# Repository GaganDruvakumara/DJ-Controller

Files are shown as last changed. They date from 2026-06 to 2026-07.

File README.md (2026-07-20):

# DIY DJ CONTROLLER
<body1 align="center">
  <br>
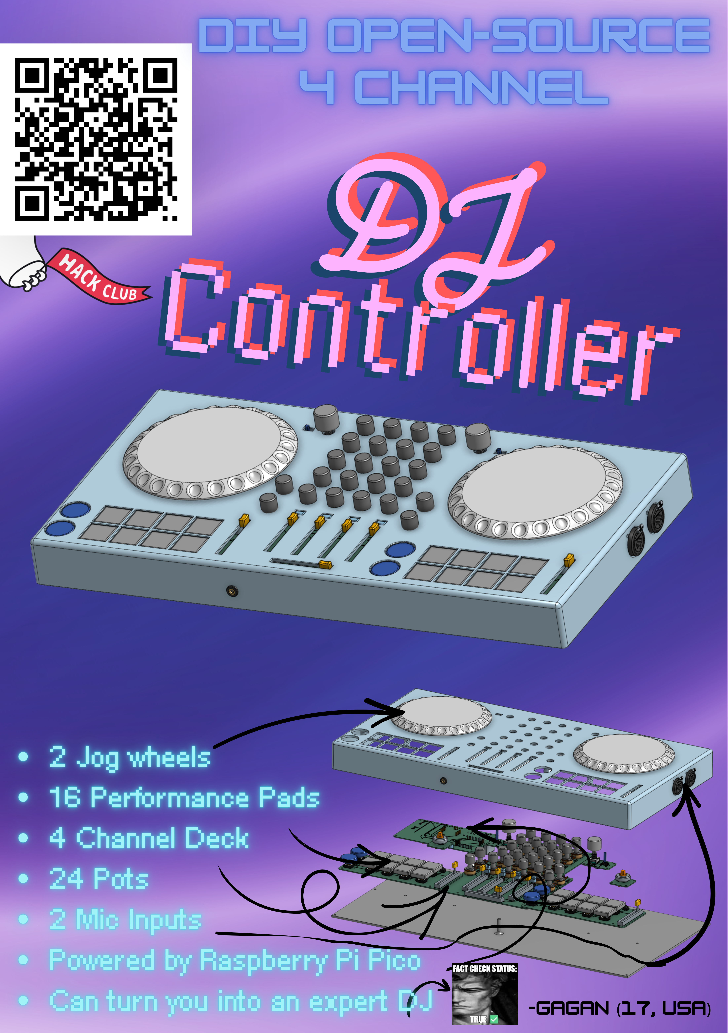
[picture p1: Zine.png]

  <br>
  I’ve wanted to get into this hobby for a while, but the cost of entry was a major barrier. I looked through existing projects online, but I couldn’t find any open-source DJ controllers that really stood out. Many were small, limited, or designed more like experimental gadgets rather than something practical for real DJ use. There seemed to be a gap between expensive commercial controllers and accessible open-source alternatives, which inspired me to create this project.
  <br>
  <br>
  <i>This project is a fully open-source, 4-channel DIY DJ controller designed to be a functional and customizable alternative for anyone interested in building their own hardware.</i>
</body1>

# Key Features
* 4 Channel Deck
* XLR & 6.35MM Jack L&R master out + 3.5mm Jack L+R master out
* 3.5mm Jack headphone out
* 32-bit DAC for outputs
* 2 Neutrik Jack Mic Inputs
* 24-bit ADC for inputs
* 16 performance pad with mode selector
* 2 rotary encoders for menu navigation

# PCB
7x 2-layer PCBs (9 total including duplicates) designed in KiCad
### PCB Schematic
PCB Schem

### PCB Front Layer


### PCB Back Layer


### PCB 3D View
Component models from GrabCad



## PCB Wiring Schematic


# CAD Assembly
CAD models designed in [Onshape](https://cad.onshape.com/documents/7791953f15b9474113af6284/w/087eac69f09fbec4411ed0d8/e/f1a33f0f3682f52a7b10a5d9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).
Assembly done with M3x5x5 threaded inserts & M3 screws. Countersunk screws are used to attach the backplate, otherwise use pan head screws for everything else.



# Bill of Materials

|Part |Min Qty.|Price Per Order|Approx. Cost|Link |
|---|---|---|---|---|
| | | | | |
|**Electronic Components** | | | | |
| | | | | |
|Raspberry Pi Pico |1 |$3.00 |$3.00 |https://www.aliexpress.us/item/3256805941727857.html|
|MCP23017 I2C GPIO Expander |3 |$1.50 |$4.50 |https://www.aliexpress.us/item/3256809349179807.html|
|CD74HC4067M Multiplexer |2 |$4.00 |$4.00 |https://www.aliexpress.us/item/3256810617508863.html|
|PCM5012 Module |2 |$2.50 |$5.00 |https://www.aliexpress.us/item/3256806137563609.html|
|PCM1808 Module |1 |$2.00 |$2.00 |https://www.aliexpress.us/item/3256811975040160.html|
|EC11 Rotary Encoder Switch |2 |$2.50 |$5.00 |https://www.aliexpress.us/item/3256804936028561.html|
|4.7k THT Resistors |38 |$1.00 |$1.00 |https://www.aliexpress.us/item/3256802303553096.html|
|10k DOIT Rotary Potentiometers |24 |$2.00 |$10.00 |https://www.aliexpress.us/item/3256809058182220.html|
|10K 60mm Slide Potentiometers (45mm travel)|7 |$2.00 |$14.00 |https://www.aliexpress.us/item/3256810149786178.html|
|600:600 Ohm Audio Transformers |2 |$7.00 |$14.00 |https://www.aliexpress.us/item/3256811824890339.html|
|100 nF Ceramic Capacitors |6 |$1.00 |$1.00 |https://www.aliexpress.us/item/3256802104127109.html|
|100 uF Electrolytic Capacitors |2 |$1.00 |$1.00 |https://www.aliexpress.us/item/3256807284223642.html|
|12mm Tacticle Switches |20 |$4.00 |$4.00 |https://www.aliexpress.us/item/2251832641145267.html|
|6mm Tacticle Switches |4 |$1.00 |$1.00 |https://www.aliexpress.us/item/2255800493650621.html|
|SPDT Slide Switch |2 |$2.00 |$2.00 |https://www.aliexpress.us/item/3256801114920515.html|
|WS2812B Individual RGB LEDs |20 |$1.50 |$3.00 |https://www.aliexpress.us/item/2255801159561004.html|
|MT6701 Magnetic Rotary Encoder |2 |$4.00 |$4.00 |https://www.aliexpress.us/item/3256810566166924.html|
| | | | | |
| | | | | |
|**IO Ports** | | | | |
| | | | | |
|XLR Male Panel Mount |2 |$1.00 |$2.00 |https://www.aliexpress.us/item/3256804030639653.html|
|6.35mm Jack Female Panel |2 |$2.00 |$4.00 |https://www.aliexpress.us/item/3256810292264986.html|
|Neutrik Combo Jack Panel |2 |$2.00 |$4.00 |https://www.aliexpress.us/item/3256801144687168.html|
|3.5mm Jack Female Panel |2 |$3.00 |$3.00 |https://www.aliexpress.us/item/3256804353386767.html|
| | | | | |
| | | | | |
|**Mechanical Components** | | | | |
| | | | | |
|M3x5x5 Threaded inserts |32 |$4.00 |$4.00 |https://www.aliexpress.us/item/3256805892791659.html|
|M3x6 Pan Head Screws |18 |$2.00 |$2.00 |https://www.aliexpress.us/item/3256802178253461.html|
|M3x15(or 14) Pan Head Screws |4 |$3.00 |$3.00 |https://www.aliexpress.us/item/3256802178253461.html|
|M3x6 Countersunk Screws |10 |$2.00 |$2.00 |https://www.aliexpress.us/item/3256808642166413.html|
|6x2mm Radial Magnet |2 |$6.00 |$6.00 |https://www.aliexpress.us/item/3256810512258917.html|
|608ZZ Bearing |2 |$2.00 |$2.00 |https://www.aliexpress.us/item/3256807356386819.html|
| | | | | |
| | | | | |
|**Total Estimated Cost** | | |$110.50 | |

### JLC PCB Order:


# Firmware

WIP

### Libraries
* Raspberry Pi Pico SDK C/C++
* Raspberry Pi Pico VS Code Extension

# Credits
* [Onshape](https://www.onshape.com/en/)
* [KiCad](https://www.kicad.org)
* [GrabCad](https://grabcad.com)

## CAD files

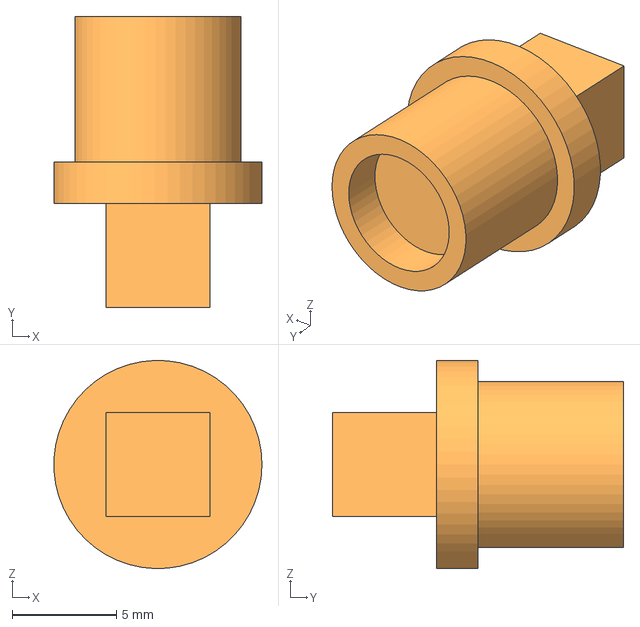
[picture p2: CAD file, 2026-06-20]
CAD Files/3D Print/EncoderMagnetMount 2x.step
9.99 x 14.0 x 10.00 mm

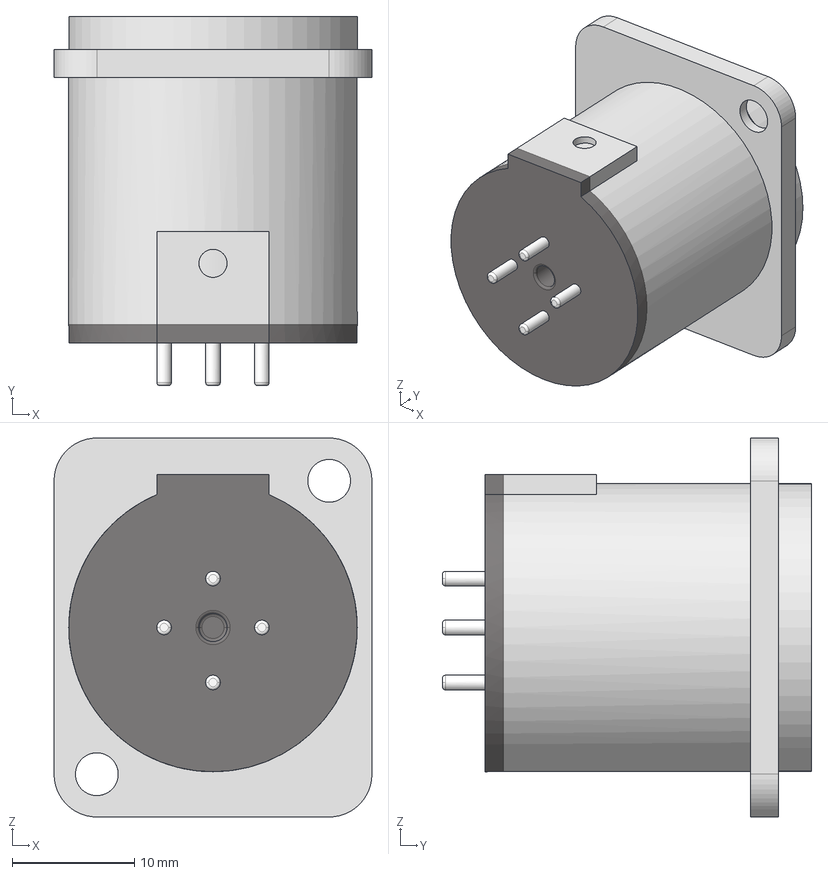
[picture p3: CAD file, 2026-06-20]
CAD Files/Only For CAD Assembly/XLR Connector PCB Mount 3 pole Male, NC3MD-V - XLRMalePanel.step
26.0 x 30.2 x 31.0 mm

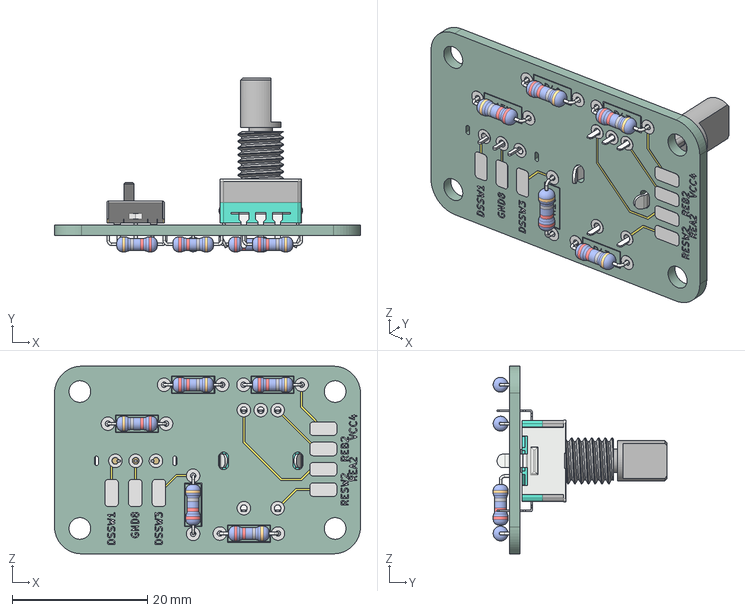
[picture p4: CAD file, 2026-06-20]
CAD Files/PCB 3D Models/LeftRE.step
45.2 x 25.7 x 27.8 mm

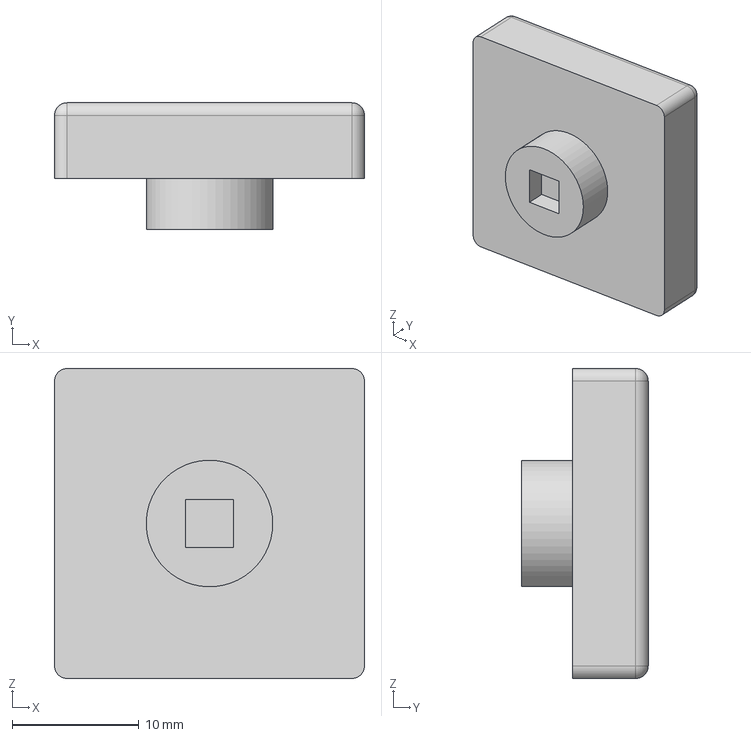
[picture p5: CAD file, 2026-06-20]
CAD Files/3D Print/PadKeycap 16x.step
24.5 x 10.0 x 24.5 mm

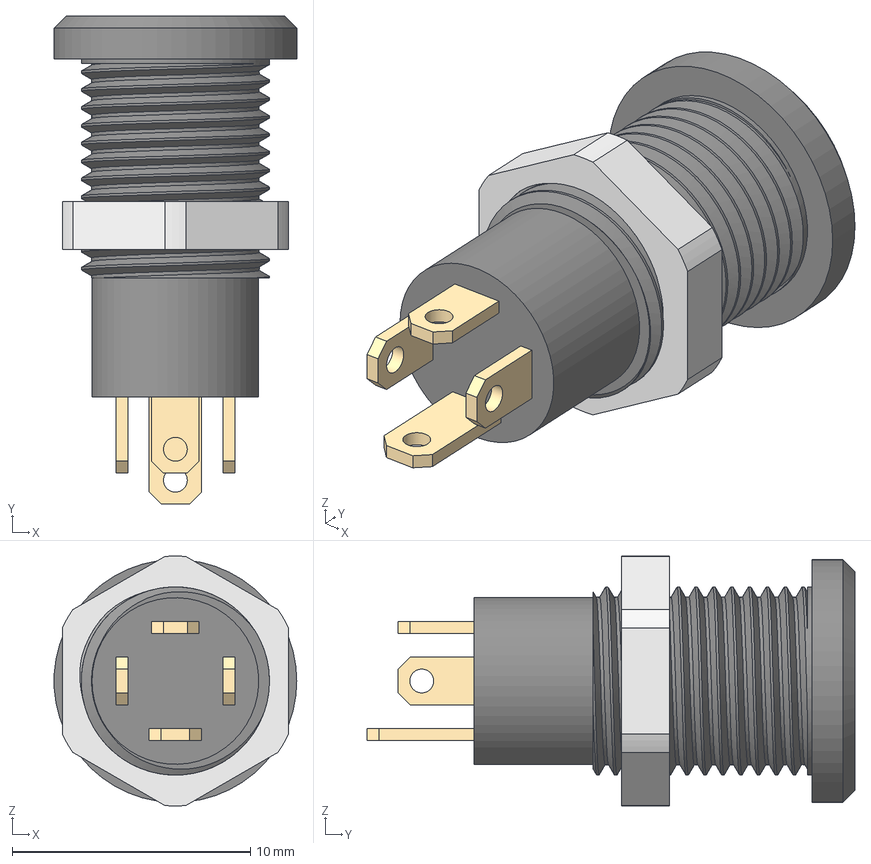
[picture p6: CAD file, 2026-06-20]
CAD Files/Only For CAD Assembly/PJ-392A-1.8-xx 3.5mm Panel Mount - 3.5mm Jack.step
10.2 x 20.5 x 10.5 mm

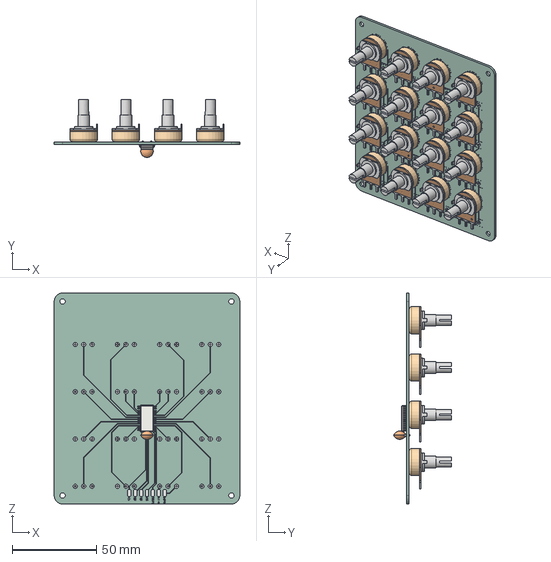
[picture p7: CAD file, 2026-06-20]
CAD Files/PCB 3D Models/EQDeck.step
110.0 x 34.3 x 125.0 mm

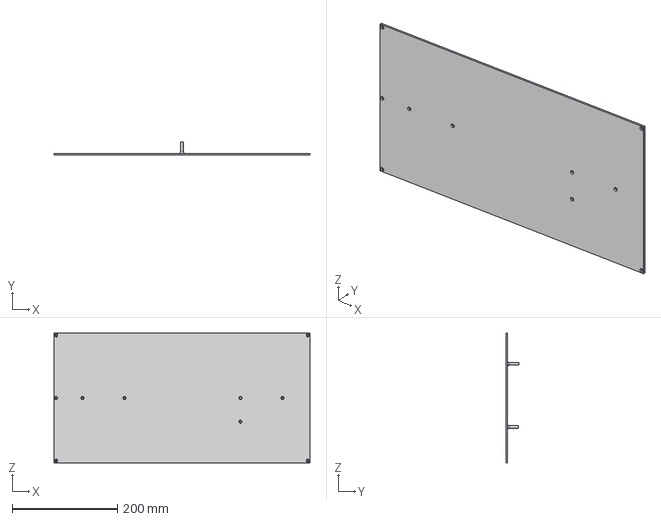
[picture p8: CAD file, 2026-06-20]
CAD Files/3D Print/CaseBackplate 1x.step
486.0 x 24.9 x 246.0 mm

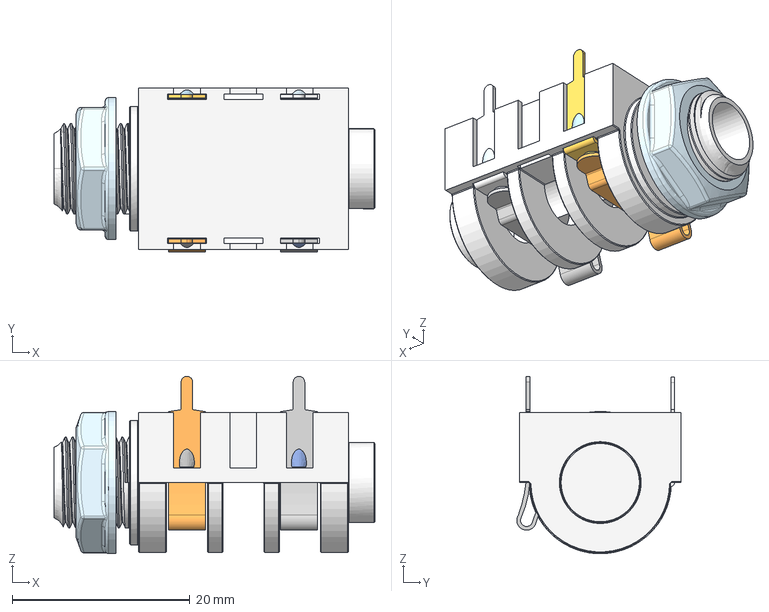
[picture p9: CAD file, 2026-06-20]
CAD Files/Only For CAD Assembly/6.35mm Mono Jack Socket Connector.step
36.1 x 18.5 x 19.9 mm

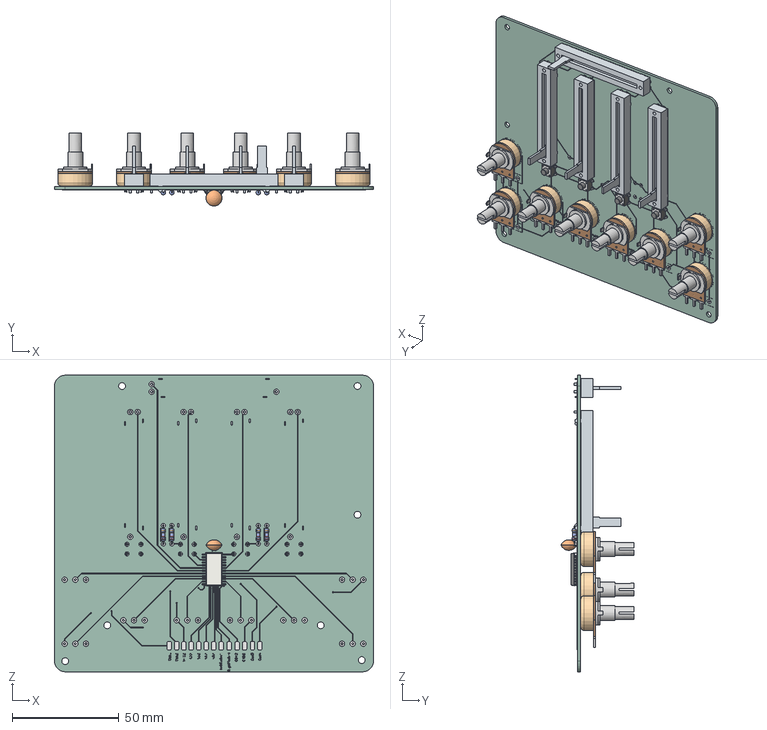
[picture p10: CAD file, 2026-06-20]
CAD Files/PCB 3D Models/FaderDeck.step
149.5 x 34.3 x 139.0 mm

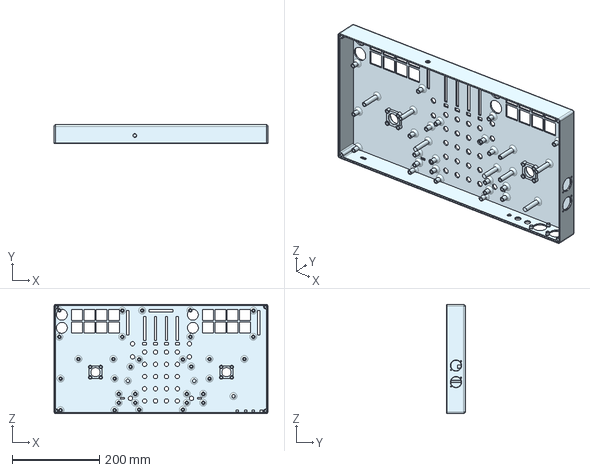
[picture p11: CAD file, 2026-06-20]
CAD Files/3D Print/CaseTop 1x.step
490.0 x 43.0 x 250.0 mm

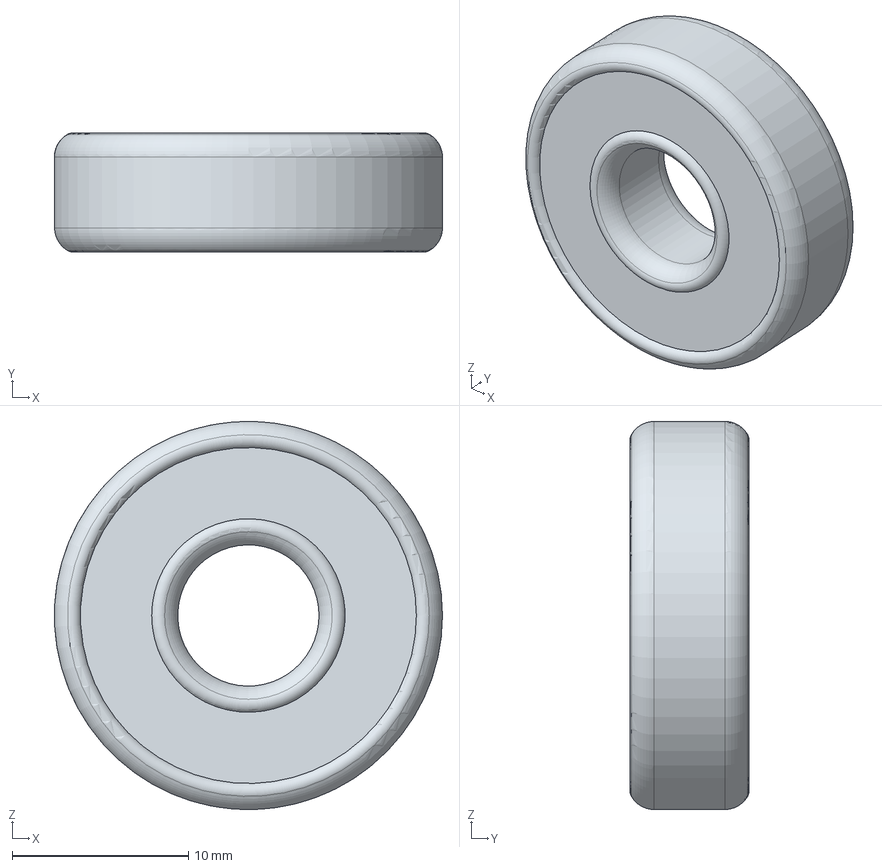
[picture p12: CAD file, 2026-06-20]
CAD Files/Only For CAD Assembly/608ZZ Bearing.step
22.0 x 6.73 x 22.0 mm

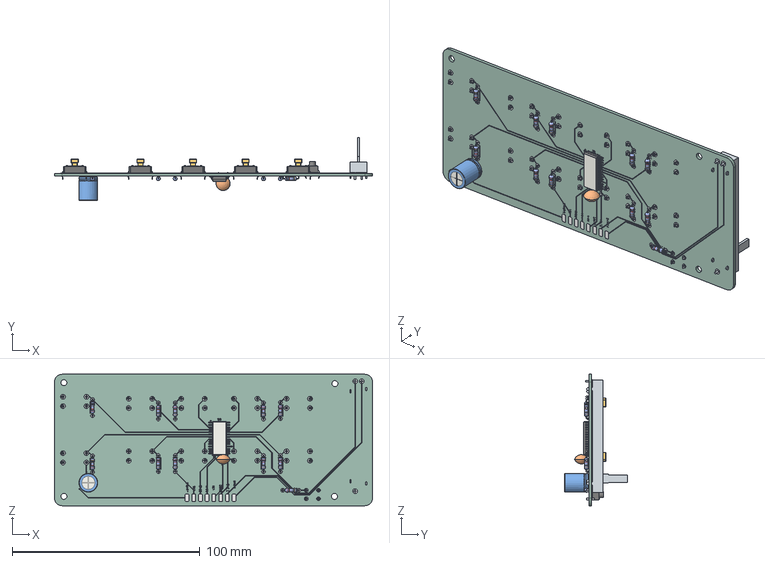
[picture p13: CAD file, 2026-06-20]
CAD Files/PCB 3D Models/PadDeck.step
169.2 x 33.3 x 70.0 mm

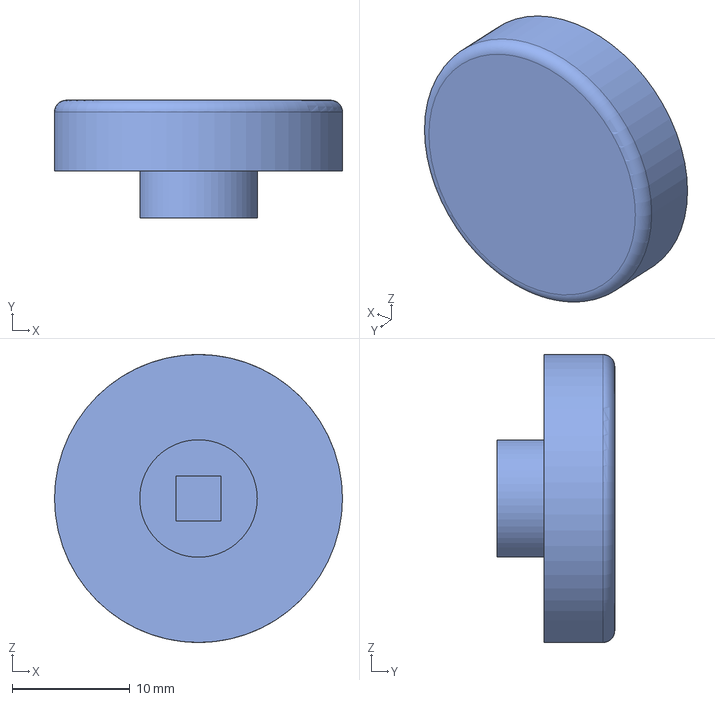
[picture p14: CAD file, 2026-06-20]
CAD Files/3D Print/PlayCueKeycap 4x.step
24.5 x 10.0 x 24.5 mm

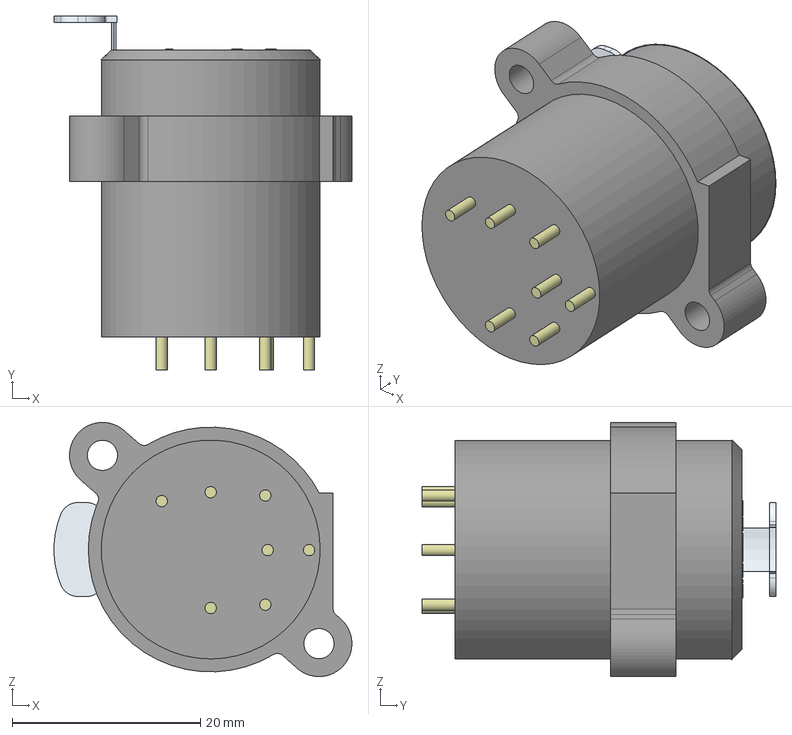
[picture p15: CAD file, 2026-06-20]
CAD Files/Only For CAD Assembly/NCJ6FI-V - NeutrikComboJack.step
31.6 x 37.6 x 27.0 mm

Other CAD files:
CAD Files/PCB 3D Models/RightRE.step
CAD Files/3D Print/RotaryEncoderKnob 2x.step
CAD Files/PCB 3D Models/JogEncoder.step
CAD Files/3D Print/ChCueKeycap 4x.step
CAD Files/3D Print/FaderKnob 7x.step
CAD Files/3D Print/Jog Wheel 2x.step
CAD Files/3D Print/PCBSpacer 2x.step
CAD Files/3D Print/PotKnob 24x.step
CAD Files/3D Print/SPDTSWExtender 2x.step

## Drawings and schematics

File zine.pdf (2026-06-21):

## DIY OPEN-SOURCE 4 CHANNEL

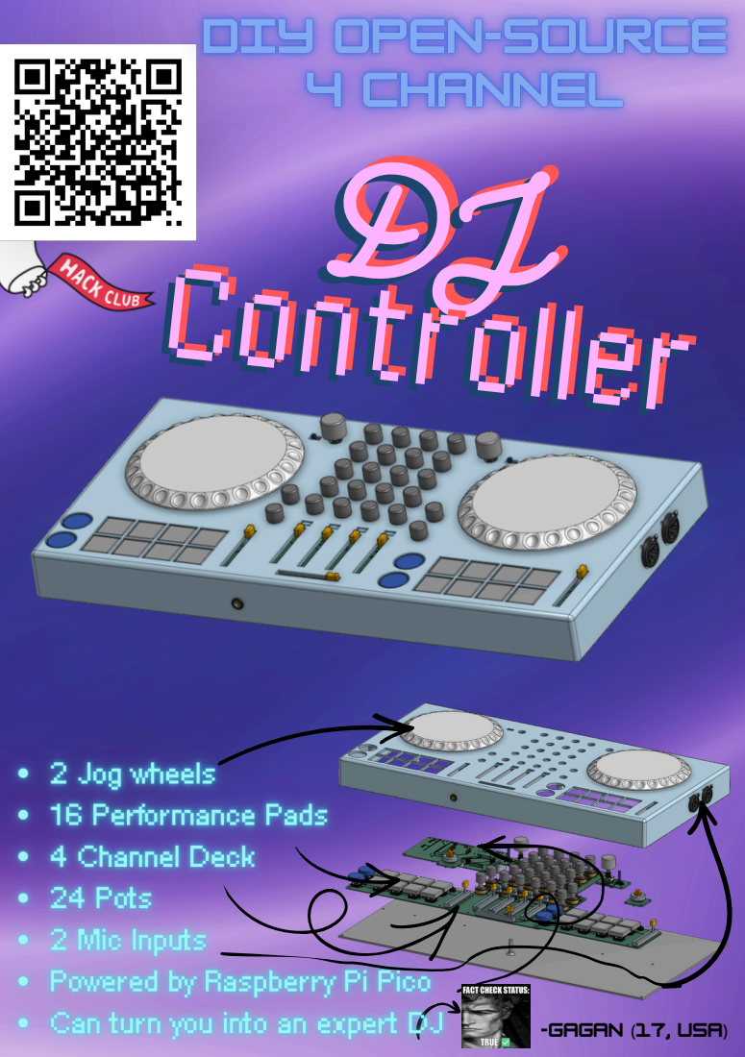
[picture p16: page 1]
DJJ; -Gagan (17, USA)

Control ler Control ler

2 Jog wheels
16 Performance Pads
4 Channel Deck
24 Pots
2 Mic Inputs
Powered by Raspberry Pi Pico
Can turn you into an expert DJ

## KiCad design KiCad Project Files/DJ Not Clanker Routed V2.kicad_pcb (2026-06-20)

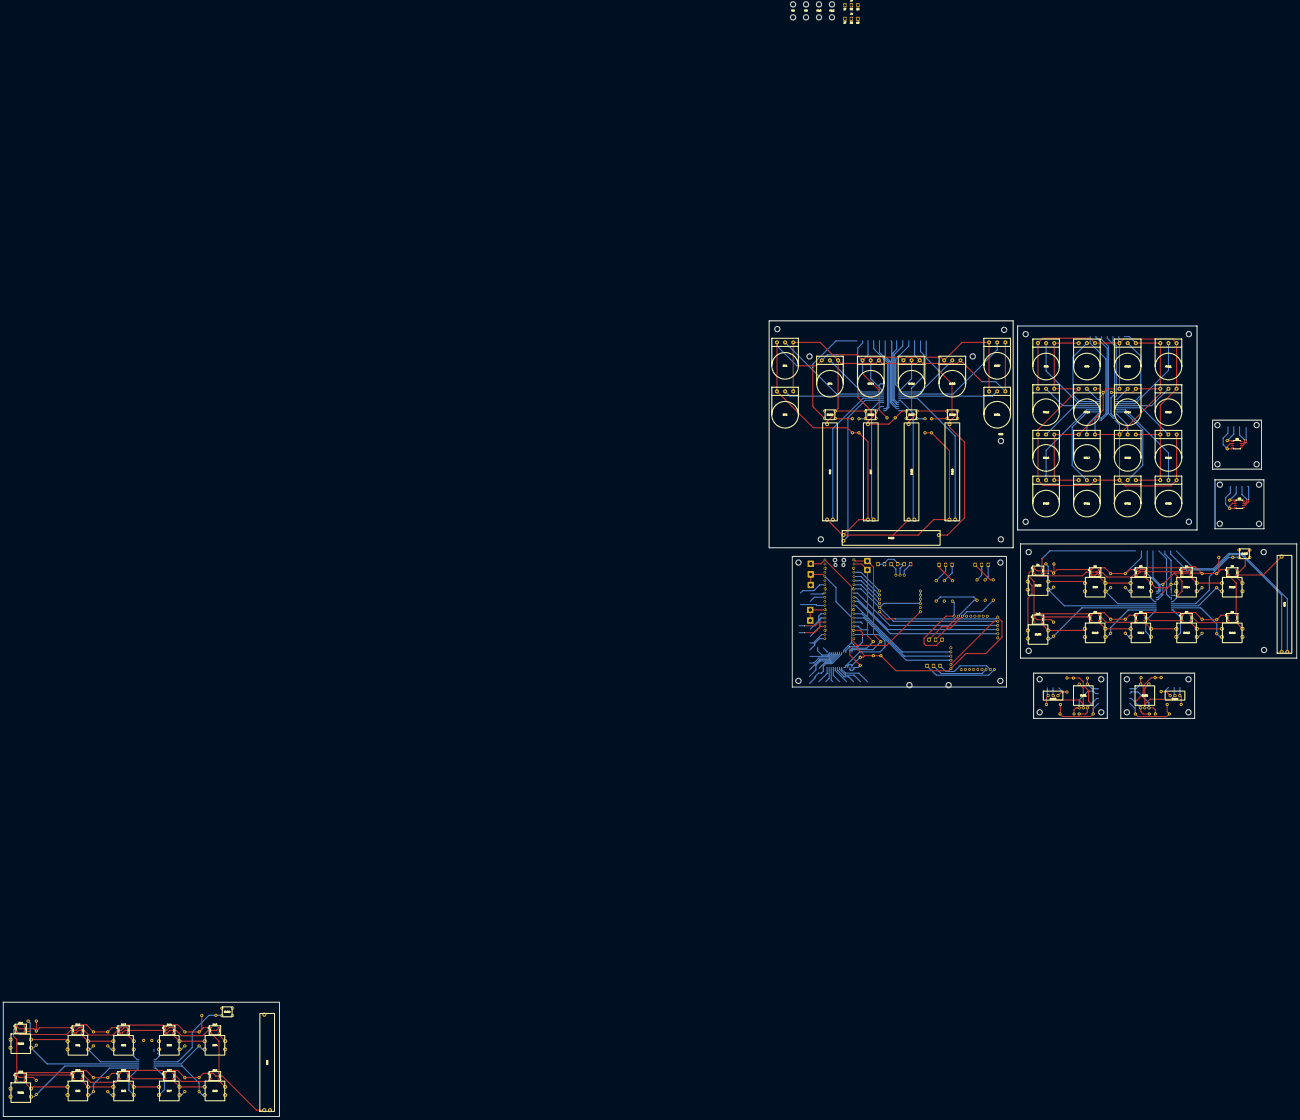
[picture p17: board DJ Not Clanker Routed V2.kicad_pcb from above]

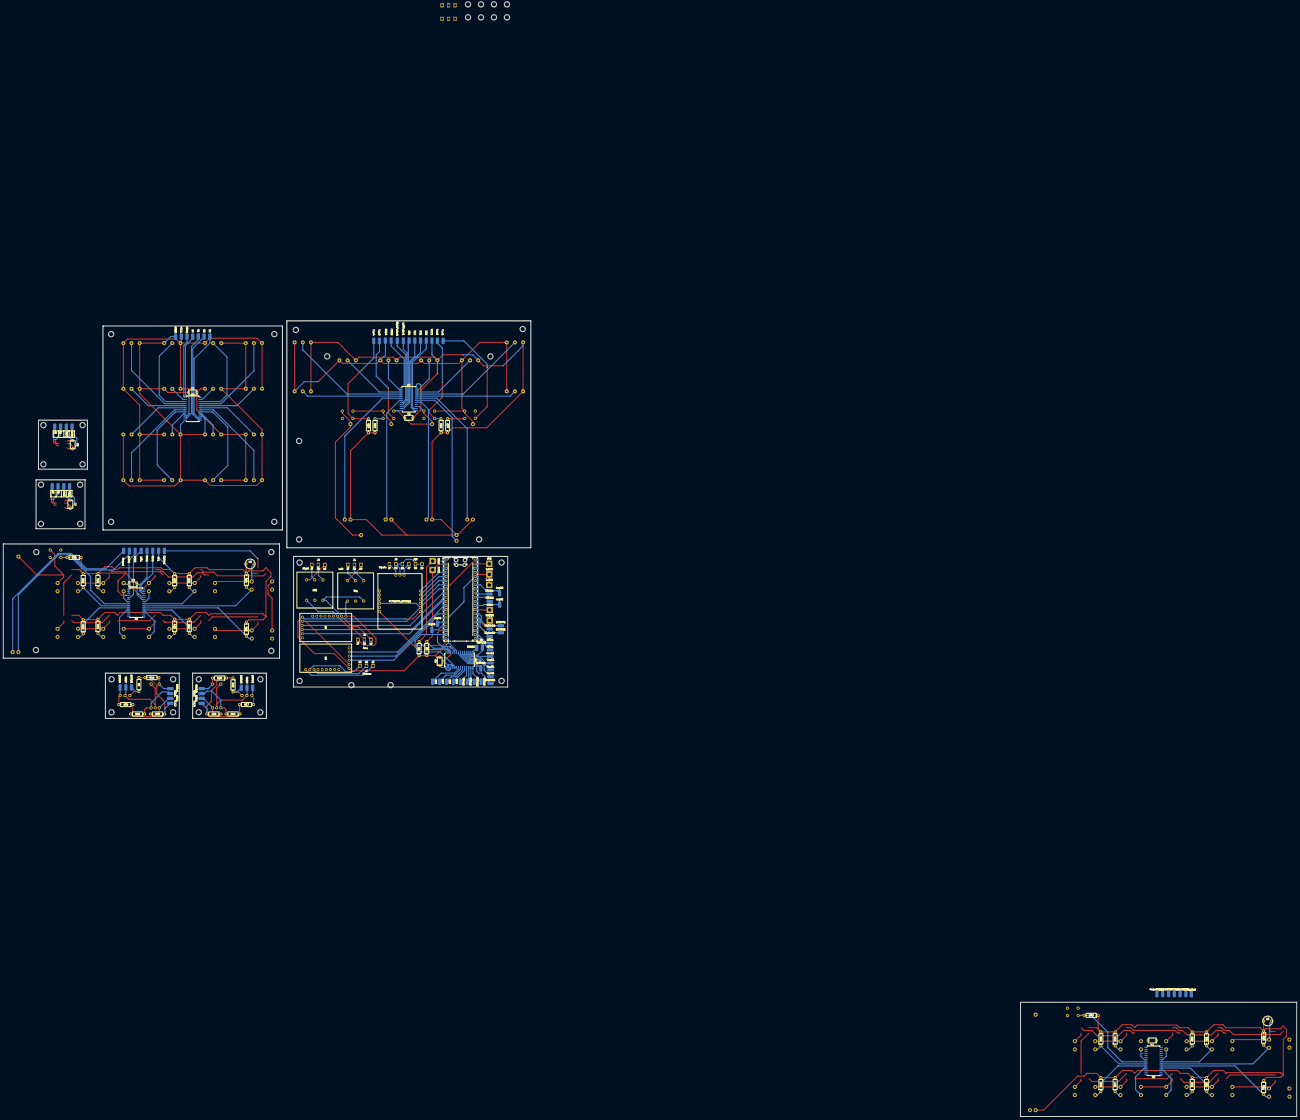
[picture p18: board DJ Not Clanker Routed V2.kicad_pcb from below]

Board: 2 copper layers, 792.6 x 487.6 mm, 286 parts (156 on the bottom side), 172 nets.

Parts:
3.3V1, 5V1: SolderWirePad_1x01_SMD_2x4mm
3.3V2, 3.3V3, 5V2: SolderWire-1.5sqmm_1x01_D1.7mm_OD3.9mm
A1: RaspberryPi_Pico; RaspberryPi_Pico_Common_Unspecified
A2, A3: SolderWirePad_1x01_SMD_2x4mm
B1, B2: SolderWirePad_1x01_SMD_2x4mm
C1, C2, C3, C4, C7, C8, C9: 0.1uF; MLCC Cap
C5, C6: 100uF; Electrolytic Cap
COM1, COM2, COM11, COM21: SolderWirePad_1x01_SMD_2x4mm
Cue1, Cue2, Cue3, Cue4, Cue11, Cue21, Cue31, Cue41: SolderWirePad_1x01_SMD_2x4mm
D1, D2, D3, D4, D5, D6, D7, D8, D9, D10, D11, D12, D13, D14, D15, D16, D17, D18, D19, D20: WS2812B; LED_WS2812B_PLCC4_5.0x5.0mm_P3.2mm
DSSW1, DSSW2, DSSW3, DSSW4, DSSW11, DSSW21, DSSW31, DSSW41: SolderWirePad_1x01_SMD_2x4mm
Fader1: SolderWirePad_1x01_SMD_2x4mm
FaderRight1: SolderWirePad_1x01_SMD_2x4mm
GND1, GND2, GND3, GND4, GND5, GND6, GND7, GND8: SolderWirePad_1x01_SMD_2x4mm
GND9, GND10: SolderWire-1.5sqmm_1x01_D1.7mm_OD3.9mm
H1, H2, H3, H4, H5, H5#2, H6, H6#2, H7, H7#2, H8, H8#2, H9, H9#2, H10, H10#2, H11, H11#2, H12, H12#2, H13, H14, H15, H16, H17, H18, H19, H20, H21, H22, H23, H24, H25, H26, H27, H28, H29, H30, H31, H32, H33, H34, H35, H36, H37: MountingHole; MountingHole_3.2mm_M3
INT1, INT2, INT11, INT21: SolderWirePad_1x01_SMD_2x4mm
J1, J2: XLR3; XLR_TRS Audio Pads
J3, J4: AudioJack3; XLR_TRS Audio Pads
J7, J9: AudioJack3; TRS Audio Pads
J8, J10: XLR3_AudioJack3_Combo; XLR_TRS Audio Pads
JogA1, JogA2: SolderWirePad_1x01_SMD_2x4mm
JogB1, JogB2: SolderWirePad_1x01_SMD_2x4mm
LeftFader1: SolderWirePad_1x01_SMD_2x4mm
Lights1, Lights2, Lights11, Lights21: SolderWirePad_1x01_SMD_2x4mm
PCM1808_BOARD1: PCM1808_Module
R5, R6, R9, R10, R11, R12, R13, R14, R15, R16, R17, R18, R19, R20, R21, R22, R23, R24, R25, R26, R27, R28, R29, R30, R31, R32, R33, R34, R35, R36, R37, R38, R43, R44, R45, R46, R47, R48: R4.7k; Resistor
REA1, REA2, REA12, REA22: SolderWirePad_1x01_SMD_2x4mm
REB1, REB2, REB12, REB22: SolderWirePad_1x01_SMD_2x4mm
RESW1, RESW2, RESW12, RESW22: SolderWirePad_1x01_SMD_2x4mm
RV1, RV4, RV5, RV8, RV9, RV10, RV11, RV12, RV13, RV14, RV15, RV16, RV17, RV18, RV19, RV20, RV21, RV22, RV23, RV24, RV26, RV27, RV30, RV31: Pot; DOIT WL Rotary Pot
RV2, RV3, RV6, RV7, RV25, RV28, RV29: Fader; 60MM Length Fader Pot
RightFader1: SolderWirePad_1x01_SMD_2x4mm
S0, S1, S02, S2, S3, S03, S12, S13, S22, S23, S32, S33: SolderWirePad_1x01_SMD_2x4mm
SCK1, SCK2: SolderWirePad_1x01_SMD_2x4mm
SCK3: SolderWire-1.5sqmm_1x01_D1.7mm_OD3.9mm
SDA1, SDA2: SolderWirePad_1x01_SMD_2x4mm
SDA3: SolderWire-1.5sqmm_1x01_D1.7mm_OD3.9mm
SW1, SW2, SW3, SW4, SW5, SW6, SW7, SW8, SW9, SW10, SW11, SW12, SW13, SW14, SW15, SW16, SW21, SW22, SW30, SW33: SW_Push; 12mm Tactile Switch
SW23, SW24, SW27, SW28, SW29, SW35: SW_Push; 6mm Tactile Switch
SW31, SW32: RotaryEncoder_Switch; EC11 Encoder Switch
SW37, SW38: SW_SPDT; SS-12F44-GXXX SPDT SW
TR1, TR2: TRANSF5; E-9818 Audio Transformer
U1, U2, U4: MCP23017x-x-SO; SOIC-28W_7.5x17.9mm_P1.27mm
U3, U7: CD74HC4067M; SOIC-24W_7.5x15.4mm_P1.27mm
U5, U6: PCM5102 Module; GY-PCM5102 DAC
U8, U9: MT6701CT; SO-8_3.9x4.9mm_P1.27mm
VCC1, VCC2, VCC3, VCC4: SolderWirePad_1x01_SMD_2x4mm
VDD1, VDD2, VDD4: SolderWirePad_1x01_SMD_2x4mm

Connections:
+3.3V: 3.3V1.1, 3.3V2.1, 3.3V3.1, A1.36 (3V3), C1.1, C2.1, C4.1, C9.1, PCM1808_BOARD1.12 (3.3V), R5.1, R6.1, R9.1, R10.1, R11.1, R13.1, R15.1, R17.1, R18.1, R19.2, R20.2, R21.2, R22.2, R23.2, R24.2, R25.2, R26.2, R27.2, R28.2, R37.2, R38.2, R43.1, R44.1, R45.2, R46.1, R47.2, R48.1, RV1.1, RV2.1, RV3.1, RV4.1, RV5.1, RV6.1, RV7.1, RV8.1, RV9.3, RV10.1, RV11.3, RV12.1, RV13.3, RV14.1, RV15.3, RV16.3, RV17.1, RV18.3, RV19.1, RV20.3, RV21.1, RV22.3, RV23.1, RV24.1, RV25.1, RV26.1, RV27.1, RV28.1, RV29.1, RV30.1, RV31.1, U2.9 (V_{DD}), U2.15 (A0), U2.18 (~RESET), U3.24 (VCC), U4.9 (V_{DD}), U4.16 (A1), U4.18 (~RESET), U5.6 (VIN), U6.6 (VIN), U7.24 (VCC), VCC1.1, VCC2.1, VCC3.1, VCC4.1, VDD4.1
+5V: 5V1.1, 5V2.1, A1.40 (VBUS), C3.1, C5.1, C6.1, D1.1 (VDD), D2.1 (VDD), D3.1 (VDD), D4.1 (VDD), D5.1 (VDD), D6.1 (VDD), D7.1 (VDD), D8.1 (VDD), D9.1 (VDD), D10.1 (VDD), D11.1 (VDD), D12.1 (VDD), D13.1 (VDD), D14.1 (VDD), D15.1 (VDD), D16.1 (VDD), D17.1 (VDD), D18.1 (VDD), D19.1 (VDD), D20.1 (VDD), PCM1808_BOARD1.6 (+5V), R12.1, R14.1, R16.1, R29.2, R30.2, R31.2, R32.2, R33.2, R34.2, R35.2, R36.2, U1.9 (V_{DD}), U1.18 (~RESET)
/COM: A1.32 (GPIO27_ADC1), COM21.1
/COM_1: A1.31 (GPIO26_ADC0), COM11.1
/DAC Outputs/MBCK: A1.11 (GPIO8), U6.2 (BCK)
/DAC Outputs/MDIN: A1.10 (GPIO7), U6.3 (DIN)
/DAC Outputs/MLRCK: A1.9 (GPIO6), U6.4 (LRCK)
/DAC Outputs/PBCK: A1.12 (GPIO9), U5.2 (BCK)
/DAC Outputs/PDIN: A1.14 (GPIO10), U5.3 (DIN)
/DAC Outputs/PLRCK: A1.15 (GPIO11), U5.4 (LRCK)
/INT1: A1.21 (GPIO16), INT11.1
/INT2: A1.22 (GPIO17), INT21.1
/Mic Inputs/BCK: A1.4 (GPIO2), PCM1808_BOARD1.7 (BCK)
/Mic Inputs/LRC: A1.6 (GPIO4), PCM1808_BOARD1.9 (LRC)
/Mic Inputs/OUT: A1.5 (GPIO3), PCM1808_BOARD1.8 (OUT)
/Mic Inputs/SCK: A1.7 (GPIO5), PCM1808_BOARD1.10 (SCK)
/Misc Switches/CueB: R13.2, SW22.2, U2.6 (GPB5)
/Misc Switches/CueCh3: Cue3.1, R19.1, SW27.2
/Misc Switches/CueCh4: Cue4.1, R20.1, SW28.2
/Misc Switches/Deck Select 2: DSSW2.1, R9.2, SW37.1 (A)
/Misc Switches/Deck Select 4: DSSW4.1, R10.2, SW37.3 (C)
/Misc Switches/PModeB: R15.2, SW24.2, U2.22 (GPA1)
/Misc Switches/PlayB: R11.2, SW21.2, U2.5 (GPB4)
/Misc Switches/SW_R1: R21.1, SW1.2, U2.7 (GPB6)
/Misc Switches/SW_R2: R22.1, SW2.2, U2.8 (GPB7)
/Misc Switches/SW_R3: R23.1, SW3.2, U2.21 (GPA0)
/Misc Switches/SW_R4: R24.1, SW4.2, U2.23 (GPA2)
/Misc Switches/SW_R5: R25.1, SW5.2, U2.4 (GPB3)
/Misc Switches/SW_R6: R26.1, SW6.2, U2.3 (GPB2)
/Misc Switches/SW_R7: R27.1, SW7.2, U2.25 (GPA4)
/Misc Switches/SW_R8: R28.1, SW8.2, U2.24 (GPA3)
/Performance Pads I2C/CueA: R14.2, SW33.2, U1.6 (GPB5)
/Performance Pads I2C/CueCh1: Cue1.1, R37.1, SW29.2
/Performance Pads I2C/CueCh2: Cue2.1, R38.1, SW35.2
/Performance Pads I2C/Deck Select 1: DSSW1.1, R17.2, SW38.1 (A)
/Performance Pads I2C/Deck Select 3: DSSW3.1, R18.2, SW38.3 (C)
/Performance Pads I2C/PModeA: R16.2, SW23.2, U1.22 (GPA1)
/Performance Pads I2C/PlayA: R12.2, SW30.2, U1.5 (GPB4)
/Performance Pads I2C/SW_L1: R29.1, SW9.2, U1.7 (GPB6)
/Performance Pads I2C/SW_L2: R30.1, SW11.2, U1.8 (GPB7)
/Performance Pads I2C/SW_L3: R31.1, SW14.2, U1.21 (GPA0)
/Performance Pads I2C/SW_L4: R32.1, SW15.2, U1.23 (GPA2)
/Performance Pads I2C/SW_L5: R33.1, SW10.2, U1.4 (GPB3)
/Performance Pads I2C/SW_L6: R34.1, SW12.2, U1.3 (GPB2)
/Performance Pads I2C/SW_L7: R35.1, SW13.2, U1.25 (GPA4)
/Performance Pads I2C/SW_L8: R36.1, SW16.2, U1.24 (GPA3)
/S0: S03.1, U4.21 (GPA0)
/S1: S13.1, U4.22 (GPA1)
/S2: S23.1, U4.23 (GPA2)
/S3: S33.1, U4.24 (GPA3)
/SCK: A1.2 (GPIO1), R6.2, SCK3.1, U4.12 (SCK)
/SDA: A1.1 (GPIO0), R5.2, SDA3.1, U4.13 (SDA)
GND: A1.3 (GND), A1.8 (GND), A1.13 (GND), A1.18 (GND), A1.23 (GND), A1.28 (GND), A1.38 (GND), C1.2, C2.2, C3.2, C4.2, C5.2, C6.2, C9.2, D1.3 (VSS), D2.3 (VSS), D3.3 (VSS), D4.3 (VSS), D5.3 (VSS), D6.3 (VSS), D7.3 (VSS), D8.3 (VSS), D9.3 (VSS), D10.3 (VSS), D11.3 (VSS), D12.3 (VSS), D13.3 (VSS), D14.3 (VSS), D15.3 (VSS), D16.3 (VSS), D17.3 (VSS), D18.3 (VSS), D19.3 (VSS), D20.3 (VSS), GND3.1, GND4.1, GND5.1, GND6.1, GND7.1, GND8.1, GND9.1, GND10.1, PCM1808_BOARD1.1 (FMY), PCM1808_BOARD1.2 (MD1), PCM1808_BOARD1.3 (MD0), PCM1808_BOARD1.4 (GND), PCM1808_BOARD1.11 (GND), RV1.3, RV2.3, RV3.3, RV4.3, RV5.3, RV6.3, RV7.3, RV8.3, RV9.1, RV10.3, RV11.1, RV12.3, RV13.1, RV14.3, RV15.1, RV16.1, RV17.3, RV18.1, RV19.3, RV20.1, RV21.3, RV22.1, RV23.3, RV24.3, RV25.3, RV26.3, RV27.3, RV28.3, RV29.3, RV30.3, RV31.3, SW1.1, SW2.1, SW3.1, SW4.1, SW5.1, SW6.1, SW7.1, SW8.1, SW9.1, SW10.1, SW11.1, SW12.1, SW13.1, SW14.1, SW15.1, SW16.1, SW21.1, SW22.1, SW23.1, SW24.1, SW27.1, SW28.1, SW29.1, SW30.1, SW31.C, SW31.S1, SW32.C, SW32.S2, SW33.1, SW35.1, SW37.2 (B), SW38.2 (B), U1.10 (V_{SS}), U1.15 (A0), U1.16 (A1), U1.17 (A2), U2.10 (V_{SS}), U2.16 (A1), U2.17 (A2), U3.12 (GND), U3.15 (~E), U4.10 (V_{SS}), U4.15 (A0), U4.17 (A2), U5.5 (GND), U6.5 (GND), U7.12 (GND), U7.15 (~E)
unnamed: A1.16 (GPIO12), JogA1.1
unnamed: A1.17 (GPIO13), JogB1.1
unnamed: A1.19 (GPIO14), U4.19 (INTB), U4.20 (INTA)
unnamed: A1.24 (GPIO18), DSSW21.1
unnamed: A1.25 (GPIO19), DSSW41.1
unnamed: A1.26 (GPIO20), Lights21.1
unnamed: A1.27 (GPIO21), Lights11.1
unnamed: A1.29 (GPIO22), JogA2.1
unnamed: A1.34 (GPIO28_ADC2), JogB2.1
unnamed: D1.4 (DIN), Lights1.1
unnamed: D1.2 (DOUT), D2.4 (DIN)
unnamed: D2.2 (DOUT), D3.4 (DIN)
unnamed: D3.2 (DOUT), D4.4 (DIN)
unnamed: D4.2 (DOUT), D5.4 (DIN)
unnamed: D5.2 (DOUT), D6.4 (DIN)
unnamed: D6.2 (DOUT), D7.4 (DIN)
unnamed: D7.2 (DOUT), D8.4 (DIN)
unnamed: D8.2 (DOUT), D9.4 (DIN)
unnamed: D9.2 (DOUT), D10.4 (DIN)
unnamed: D11.4 (DIN), Lights2.1
unnamed: D11.2 (DOUT), D12.4 (DIN)
unnamed: D12.2 (DOUT), D13.4 (DIN)
unnamed: D13.2 (DOUT), D14.4 (DIN)
unnamed: D14.2 (DOUT), D15.4 (DIN)
unnamed: D15.2 (DOUT), D16.4 (DIN)
unnamed: D16.2 (DOUT), D17.4 (DIN)
unnamed: D17.2 (DOUT), D18.4 (DIN)
unnamed: D18.2 (DOUT), D19.4 (DIN)
unnamed: D19.2 (DOUT), D20.4 (DIN)
unnamed: Fader1.1, RV2.2
unnamed: FaderRight1.1, RV6.2
unnamed: J1.1, TR1.5
unnamed: J1.2, TR1.4
unnamed: J1.3, TR1.6
unnamed: J2.1, TR2.5
unnamed: J2.2, TR2.4
unnamed: J2.3, TR2.6
unnamed: J7.S, U5.14 (AGND)
unnamed: J9.S, TR1.1, TR2.1, U6.14 (AGND)
unnamed: J8.1, J8.3, J10.1, J10.3, PCM1808_BOARD1.14 (-)
unnamed: J10.2, PCM1808_BOARD1.15 (LIN)
unnamed: J8.2, PCM1808_BOARD1.13 (RIN)
unnamed: R43.2, RESW2.1, SW31.S2
unnamed: R44.2, RESW1.1, SW32.S1
unnamed: R45.1, REB1.1, SW32.B
unnamed: R46.2, REA1.1, SW32.A
unnamed: R47.1, REB2.1, SW31.B
unnamed: R48.2, REA2.1, SW31.A
unnamed: INT1.1, U1.19 (INTB), U1.20 (INTA)
unnamed: SCK1.1, U1.12 (SCK)
unnamed: SDA1.1, U1.13 (SDA)
unnamed: INT2.1, U2.19 (INTB), U2.20 (INTA)
unnamed: SCK2.1, U2.12 (SCK)
unnamed: SDA2.1, U2.13 (SDA)
unnamed: COM1.1, U3.1 (COM)
unnamed: RV18.2, U3.9 (I0)
unnamed: RV22.2, U3.8 (I1)
unnamed: RV23.2, U3.7 (I2)
unnamed: RV19.2, U3.6 (I3)
unnamed: RV15.2, U3.5 (I4)
unnamed: RV11.2, U3.4 (I5)
unnamed: RV10.2, U3.3 (I6)
unnamed: RV14.2, U3.2 (I7)
unnamed: RV13.2, U3.23 (I8)
unnamed: RV9.2, U3.22 (I9)
unnamed: RV8.2, U3.21 (I10)
unnamed: RV12.2, U3.20 (I11)
unnamed: RV16.2, U3.19 (I12)
unnamed: RV20.2, U3.18 (I13)
unnamed: RV21.2, U3.17 (I14)
unnamed: RV17.2, U3.16 (I15)
unnamed: S0.1, U3.10 (S0)
unnamed: S1.1, U3.11 (S1)
unnamed: S2.1, U3.14 (S2)
unnamed: S3.1, U3.13 (S3)
unnamed: REA12.1, U4.25 (GPA4)
unnamed: REB12.1, U4.26 (GPA5)
unnamed: RESW12.1, U4.27 (GPA6)
unnamed: REB22.1, U4.28 (GPA7)
unnamed: REA22.1, U4.1 (GPB0)
unnamed: RESW22.1, U4.2 (GPB1)
unnamed: Cue11.1, U4.3 (GPB2)
unnamed: Cue21.1, U4.4 (GPB3)
unnamed: Cue31.1, U4.5 (GPB4)
unnamed: Cue41.1, U4.6 (GPB5)
unnamed: DSSW11.1, U4.7 (GPB6)
unnamed: DSSW31.1, U4.8 (GPB7)
unnamed: J7.T, U5.15 (LROUT)
unnamed: J7.R, U5.13 (ROUT)
unnamed: J9.T, TR1.3, U6.15 (LROUT)
unnamed: J9.R, TR2.3, U6.13 (ROUT)
unnamed: COM2.1, U7.1 (COM)
unnamed: LeftFader1.1, U7.9 (I0)
unnamed: RightFader1.1, U7.8 (I1)
unnamed: RV25.2, U7.7 (I2)
unnamed: RV29.2, U7.6 (I3)
unnamed: RV31.2, U7.5 (I4)
unnamed: RV27.2, U7.4 (I5)
unnamed: RV30.2, U7.3 (I6)
unnamed: RV26.2, U7.2 (I7)
unnamed: RV24.2, U7.23 (I8)
unnamed: RV4.2, U7.22 (I9)
unnamed: RV1.2, U7.21 (I10)
unnamed: RV5.2, U7.20 (I11)
unnamed: RV3.2, U7.19 (I12)
unnamed: RV28.2, U7.18 (I13)
unnamed: RV7.2, U7.17 (I14)
unnamed: S02.1, U7.10 (S0)
unnamed: S12.1, U7.11 (S1)
unnamed: S22.1, U7.14 (S2)
unnamed: S32.1, U7.13 (S3)
unnamed: A3.1, U8.6 (A)
unnamed: B2.1, U8.7 (B)
unnamed: C7.2, GND2.1, U8.2 (MODE), U8.4 (GND)
unnamed: C7.1, U8.1 (VDD), VDD2.1
unnamed: A2.1, U9.6 (A)
unnamed: B1.1, U9.7 (B)
unnamed: C8.2, GND1.1, U9.2 (MODE), U9.4 (GND)
unnamed: C8.1, U9.1 (VDD), VDD1.1

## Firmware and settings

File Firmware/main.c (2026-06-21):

//there's a lot of skeleton code because I've never done stuff like this before & it's basically impossible to do without a prototype, but this should set up the basic structure of the code

#include <stdio.h>
#include "./pico/stdlib.h"
#include "definitions.h"

int LPadState[2][5] = {{0, 0, 0, 0, 0}, {0, 0, 0, 0, 0}};
int RPadState[2][5] = {{0, 0, 0, 0, 0}, {0, 0, 0, 0, 0}};
int DSSWState[2] = {0, 0};
int lightStatesL[5][3] = {{{0, 0, 0}, {0, 0, 0}, {0, 0, 0}, {0, 0, 0}, {0, 0, 0}}, 
                          {{0, 0, 0}, {0, 0, 0}, {0, 0, 0}, {0, 0, 0}, {0, 0, 0}}};
int lightStatesR[5][3] = {{{0, 0, 0}, {0, 0, 0}, {0, 0, 0}, {0, 0, 0}, {0, 0, 0}}, 
                          {{0, 0, 0}, {0, 0, 0}, {0, 0, 0}, {0, 0, 0}, {0, 0, 0}}};

int jogPositions[2] = {0, 0}; // I don't know how to store encoder positions yet, so this is a placeholder for now
int REPositions[2] = {0, 0};


void init() {
    gpio_set_direction(Pad1INT, GPIO_IN);
    gpio_set_direction(Pad2INT, GPIO_IN);
    gpio_set_direction(MainExpINT, GPIO_IN);
    adc_gpio_init(COM1);
    adc_gpio_init(COM2);
    // initialize I2C stuff
}

void pollExpanders(int address) {
    // This function should read the state of the expanders and update LPadState and RPadState accordingly
}

void pollMuxes() {
    // This function should read the state of the multiplexers and return pot values
    for (int i = 0; i < 16; i++) {
        int emptyAdress = 0;
        //set mux address
        if(emptyAdress!=0){
            adc_set_input(COM1);
            adc_read(COM1);
            adc_set_input(COM2);
            adc_read(COM2);
        }
        //update midi values based on pot values
    }
}

void updateLightStates() {
    // This function should update the light states based on the current state of the pads and switches and return true if any light state has changed, false otherwise
}

void updateLights() {
    // This function should update the lights based on the current light states
}

void pollJog() {
    // This function should read the state of the jogs and update LPadState and RPadState accordingly
}

void pollRE() {
    // This function should read the state of the rotary encoders and update REPositions accordingly
}

void processAudioInputs() {
    // This function should process audio inputs
}

void GetDJAudio() {
    // This function should get the the audio from the DJ software so that it can be processed and sent to the master output and phones output
}

void processMasterOut() {
    // This function should process the master output
}

void processPhonesOut() {
    // This function should process the phones output
}

void updateMidi() {
    // This function should process the midi output
}



int main() {
    int placeholder = 0;
    stdio_init_all();
    init();
    while (true) {
        if (gpio_get(Pad1INT)) {
            pollExpanders(placeholder);
        }
        if (gpio_get(Pad2INT)) {
            pollExpanders(placeholder);
        }
        if (gpio_get(MainExpINT)) {
            pollExpanders(placeholder);
        }
    }
    pollMuxes();
    if (updateLightStates(placeholder)) {
        updateLights(placeholder);
    }
    if(gpio_get(DSSW2) != DSSWState[0] || gpio_get(DSSW4) != DSSWState[1]) {
        DSSWState[0] = gpio_get(DSSW2);
        DSSWState[1] = gpio_get(DSSW4);
    }
    pollJog();
    pollRE();
    processAudioInputs();
    updateMidi();
    GetDJAudio();
    processMasterOut();
    processPhonesOut();
}

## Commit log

2026-06-20 added Cad files
    [6.35mm Mono Jack Socket Connector.step, 608ZZ Bearing.step, CaseBackplate 1x.step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]
2026-06-20 added lots of files
    [DAC Outputd.kicad_sch, DJ Not Clanker Routed V2.kicad_pcb, DJ Not Clanker Routed V2.kicad_sch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]
2026-06-21 Add PCB section with schematic to README
    Added PCB section with schematic image to README.
2026-06-21 Enhance README with PCB and CAD details
    Added detailed PCB schematics and CAD assembly images.
2026-06-21 added zine
    [BOM.csv]
2026-06-21 updated BOM
    [BOM.csv]
2026-06-21 Update README with PCB Back Layer and 3D View
    Added PCB Back Layer and PCB 3D View sections with images.
2026-06-22 updated BOM format from TSV to CSV
    [BOM.csv]
2026-06-22 Add Bill of Materials to README
    Added a Bill of Materials section with detailed parts list including quantities, prices, and links.
2026-06-22 Update Bill of Materials with new sections
2026-06-22 Update Bill of Materials section in README
2026-06-22 Fix formatting issues in BOM.csv
    Removed extra spaces in the BOM.csv file and ensured consistent formatting for prices and links.
    [BOM.csv]
2026-06-22 Clarify assembly instructions in README
    Added details about screw types for assembly.
2026-07-20 Add JLC PCB Order image to README
    Added JLC PCB Order image to README.
2026-07-20 Update JLC PCB Order section header in README
